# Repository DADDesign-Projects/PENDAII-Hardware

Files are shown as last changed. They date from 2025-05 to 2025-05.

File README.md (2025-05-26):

# PENDAII: Platform for Effects oN DAisy

Welcome to the **PENDAII** project! This repository contains the schematics and PCB layouts created with **KiCad 9.0** for a digital audio effects platform based on the **Daisy-Seed** board from **ElectroSmith**.

## Author

**DAD Design**

## Overview / Features

**PENDAII** is the second version of the PENDA platform. It introduces stereo processing and improved management of signal paths and power supplies.

**What’s New in PENDAII**:

- **Stereo processing**: a second audio channel has been added for a wider and more immersive sound experience.
- **Digital input volume control**: the input gain is now precisely adjustable via a digital potentiometer.
- **Digital Dry/Wet mix control**: the ratio between the processed (wet) and original (dry) signal is digitally managed.
- **100% analog Dry path**: although controlled digitally, the dry signal remains fully analog to preserve audio quality.

**General Features**:

- **Mono or Stereo Audio Input/Output**: flexible integration into various audio setups.
- **Two momentary footswitches**: for hands-free activation of effects.
- **2-inch SPI display**: clean and compact user interface (compatible with most ST7789 displays).
- **MIDI input**: allows control via external MIDI devices.
- **User controls**:
  - **4 encoders with push-button**: for parameter navigation and adjustment.
  - **3 analog potentiometers**: for direct control of parameters such as input level or Dry/Wet mix.

## Content

- The **Fab** directory contains all necessary files for fabrication.
- The **PENDAII-Hardware** directory contains the source files for the KiCad 9.0 project.

## Software

**PENDAII-Software** is a collection of audio effects built on an advanced software architecture, specifically designed for the PENDAII hardware platform.

[GitHub Repository](https://github.com/DADDesign-Projects/PENDAII-Software)

## Contributing

Contributions are welcome! If you'd like to suggest an improvement or fix an issue, feel free to open an *issue* or a *pull request*.

## License

This project is licensed under the **MIT License**.

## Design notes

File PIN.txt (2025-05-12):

Encoder0
A	PA0/D25
B	PD11/D26
SW	PA1/D24

Encoder1
A 	PA7/D18
B   PA6/D19
SW  PB1/D17

Encoder2
A	PA5/D22
B   PA0/D16
SW  PC0/D15

Encoder3
A   PB8/D11
B   PB9/D12
SW  PG10/D7

FootSwitch1 PG9/D27

FootSwitch2 PA2/D28

TFT_Reset   PC1/D20
TFT_DC		PC4/D21
TFT_MOSI	PB5/D10
TFT_SCK		PG11/D8

SSPI
SDATA       PC11/D1
CLK         PC10/D2
CS          PC9/D3
MUTE        D4

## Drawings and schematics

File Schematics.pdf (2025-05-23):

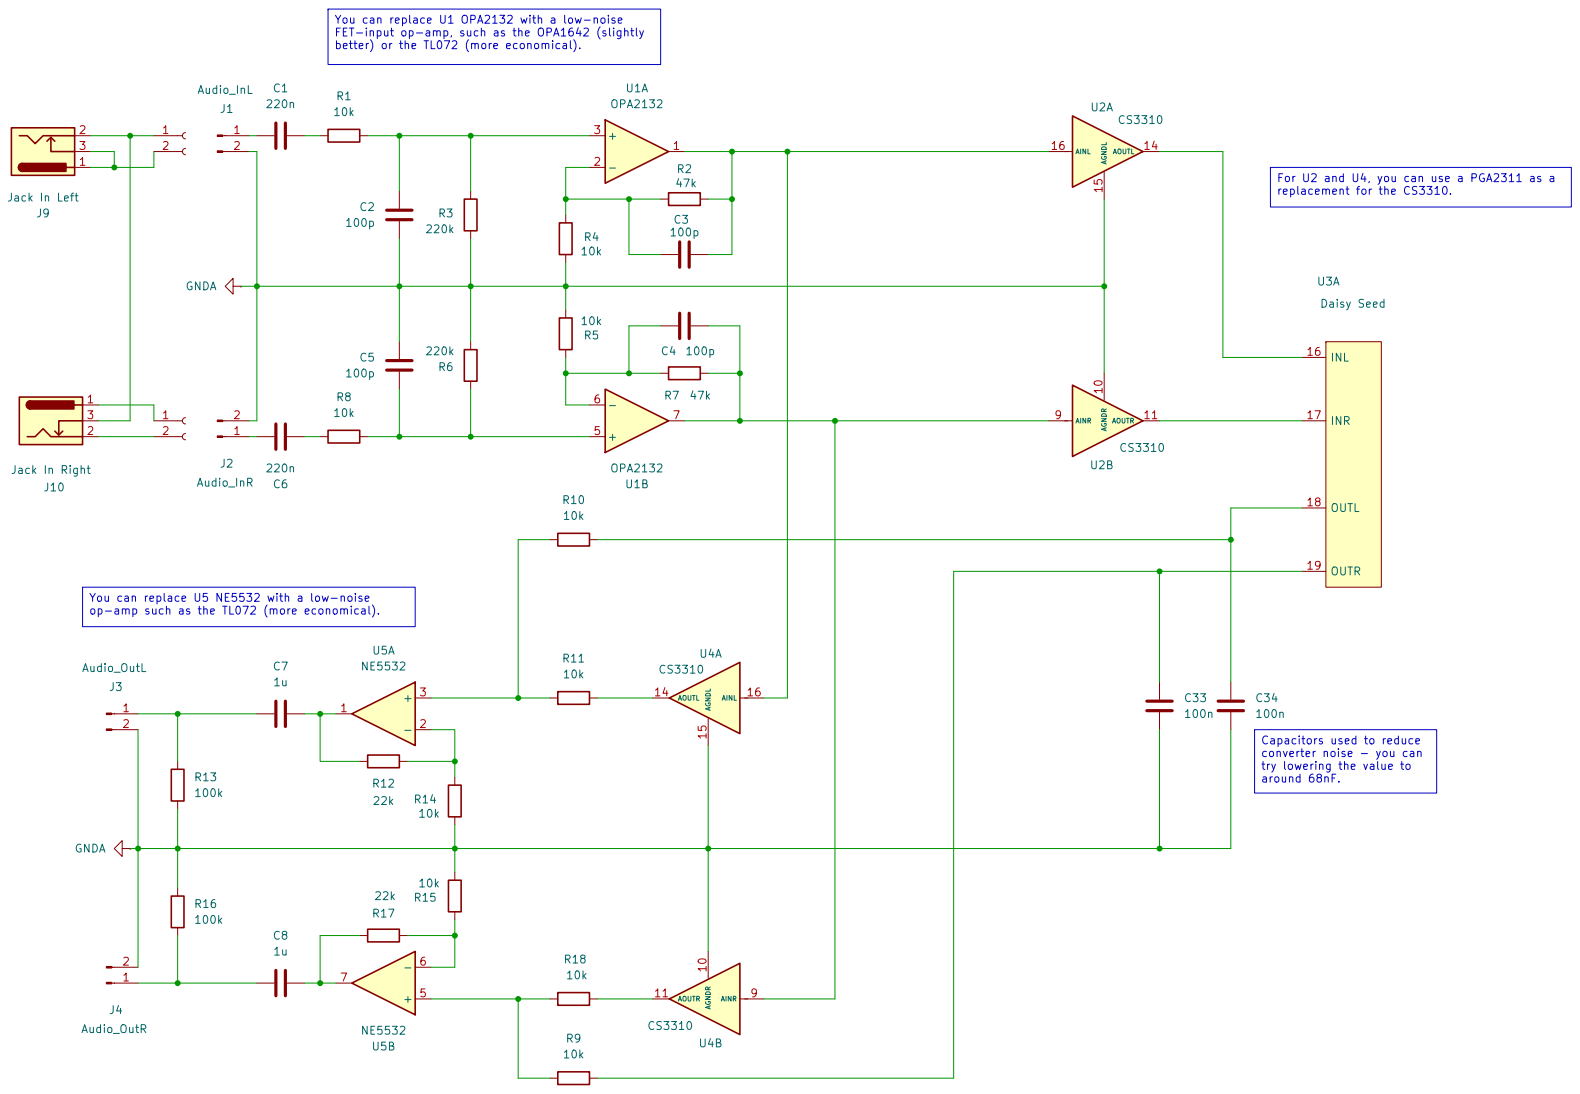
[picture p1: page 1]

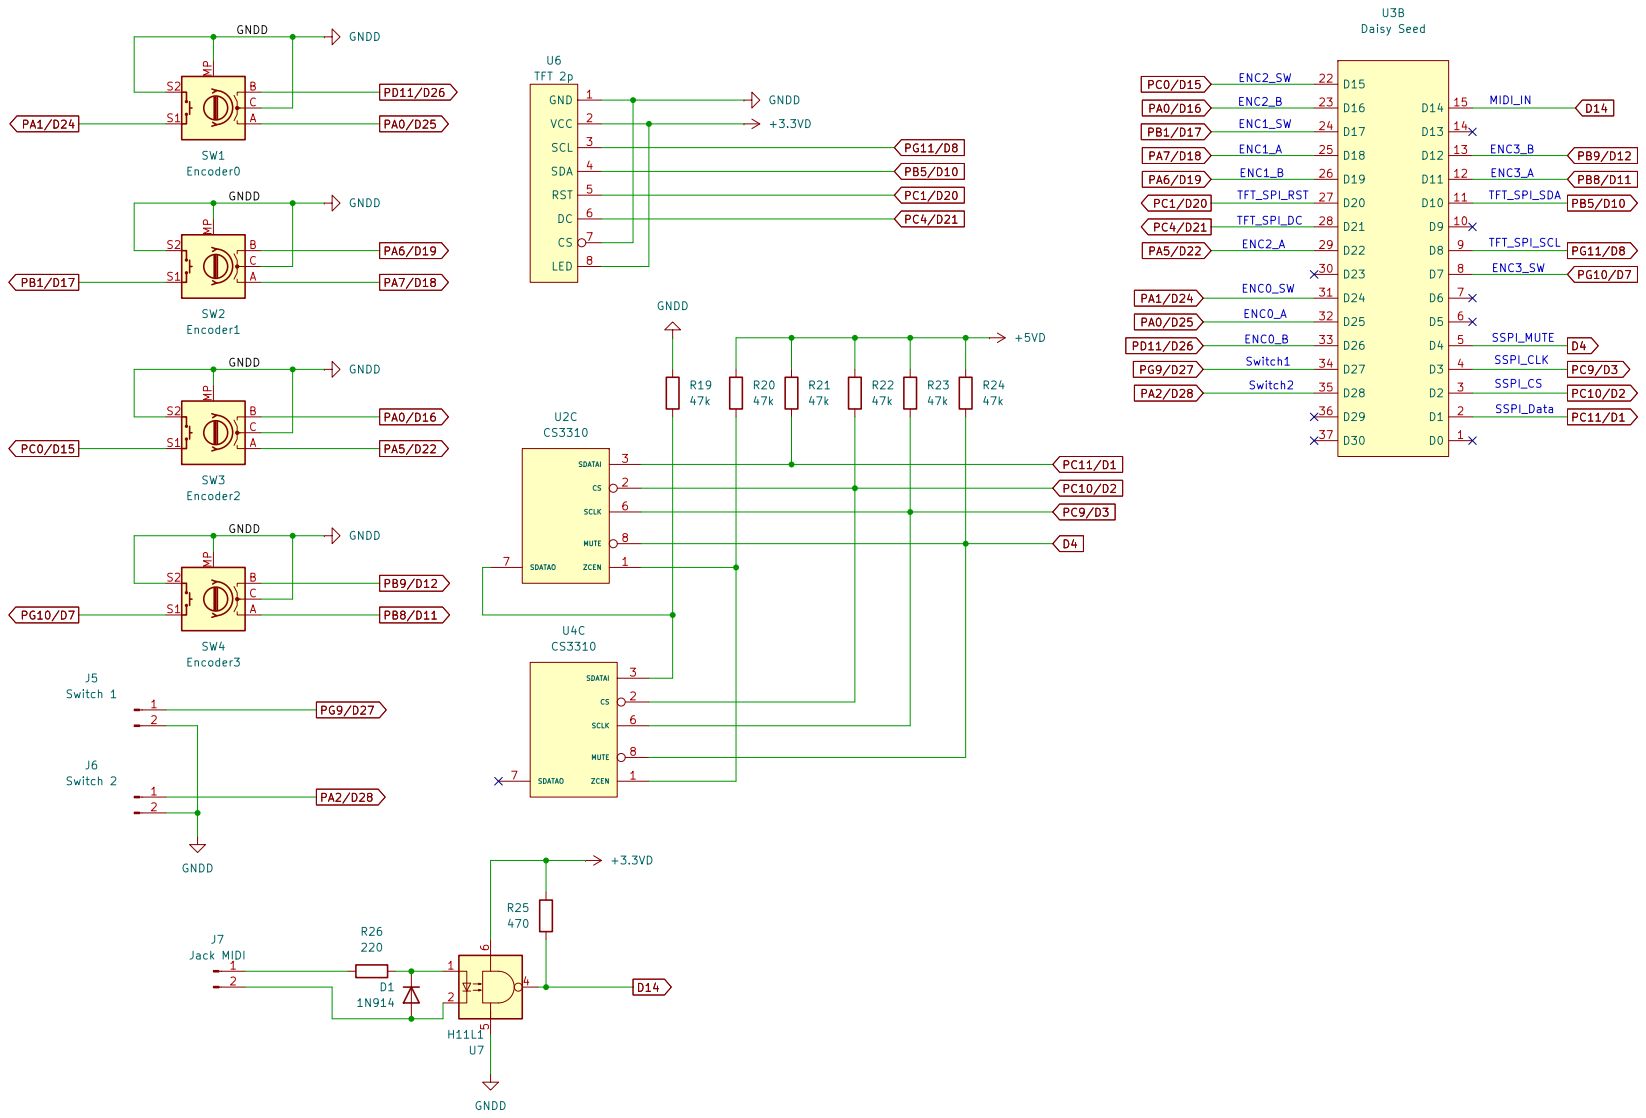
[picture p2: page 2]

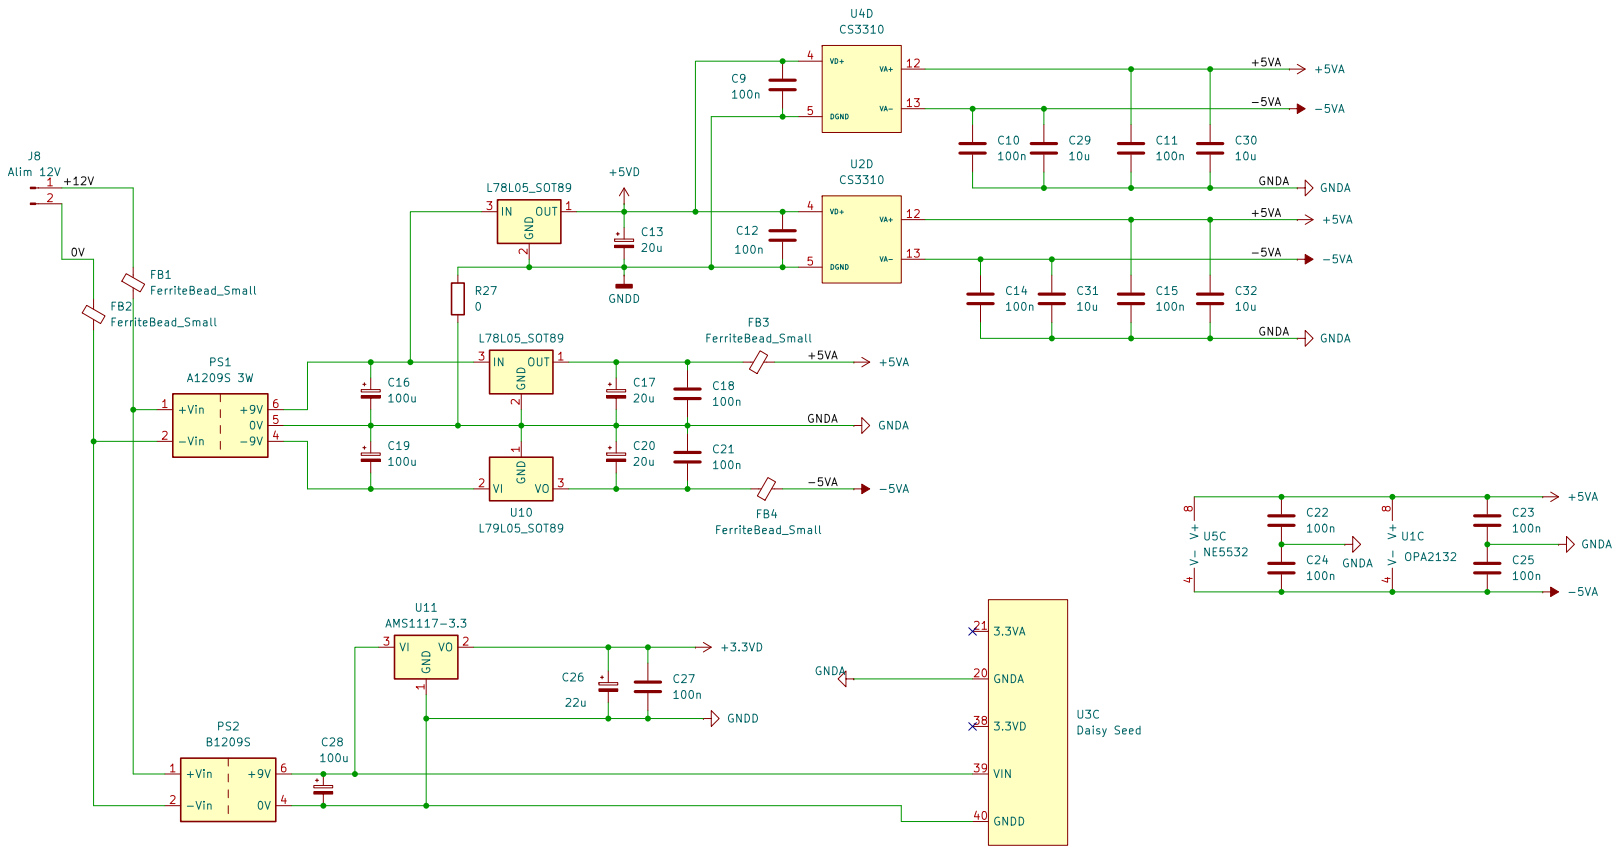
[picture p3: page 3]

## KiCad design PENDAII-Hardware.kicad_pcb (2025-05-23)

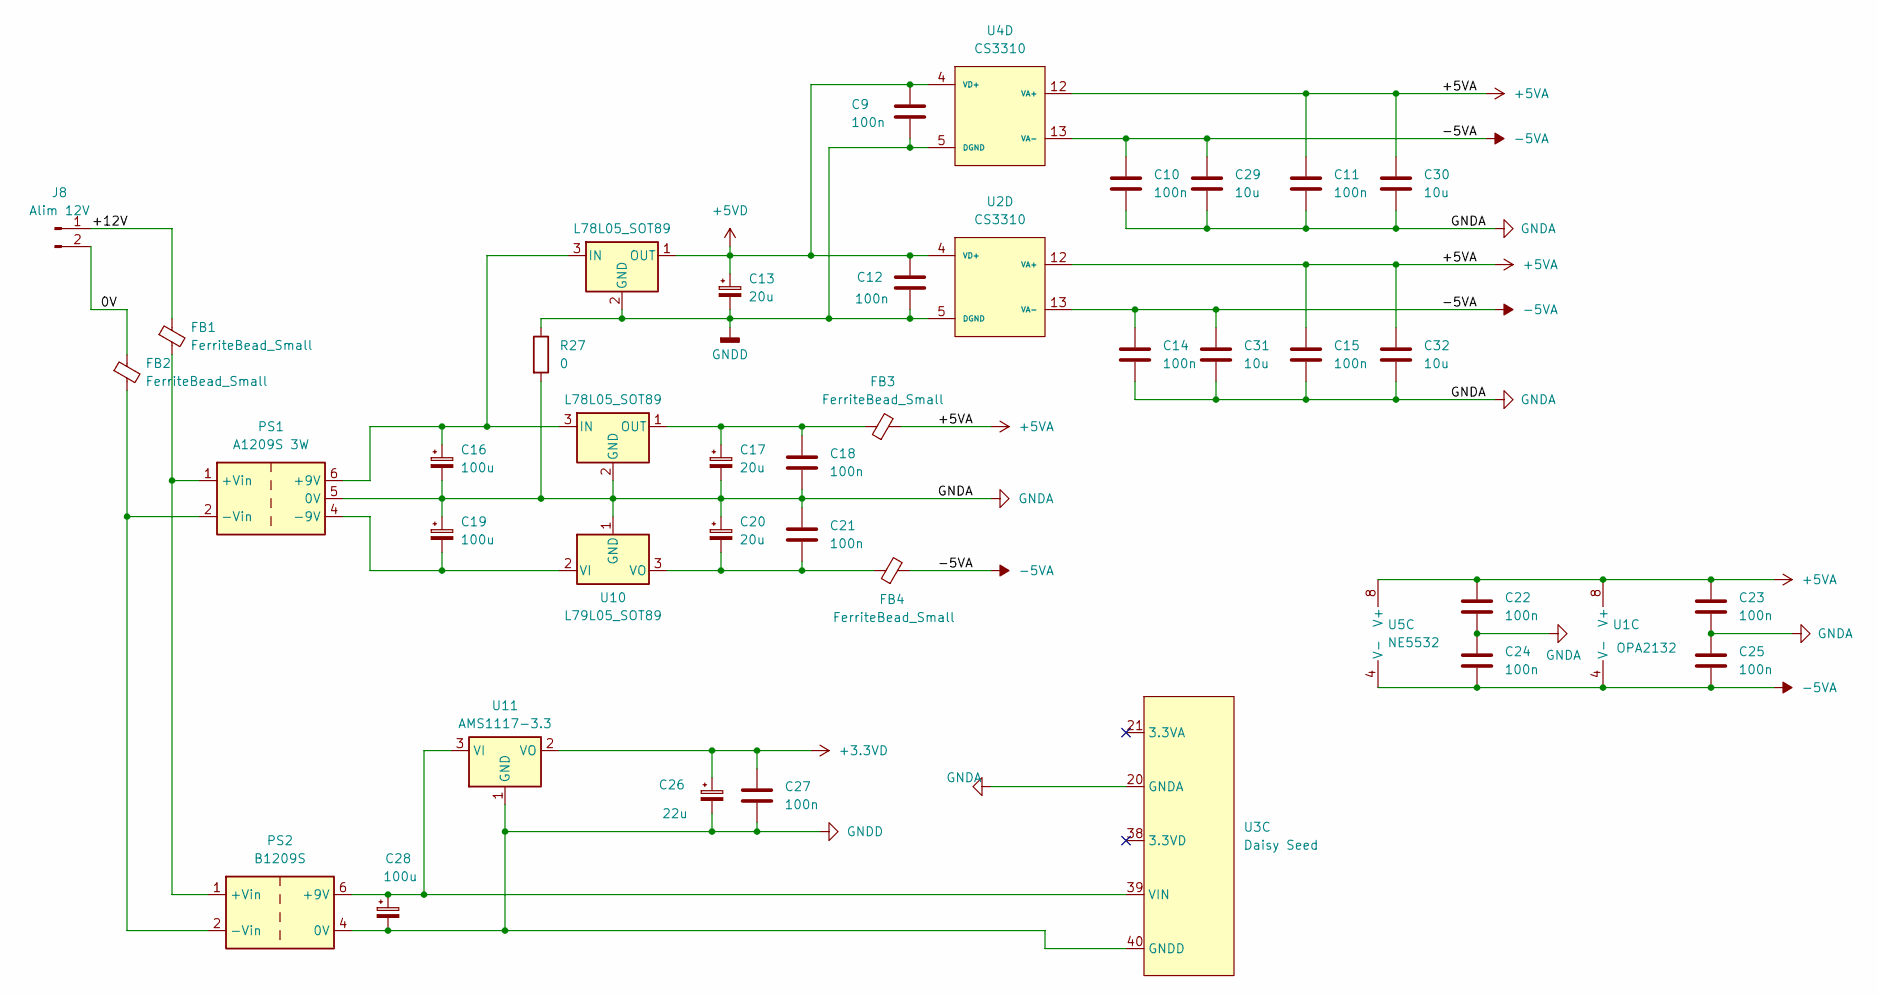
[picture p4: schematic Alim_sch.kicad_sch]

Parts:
C9, C10, C11, C12, C14, C15, C18, C21, C22, C23, C24, C25, C27: 100n; C_0805_2012Metric_Pad1.18x1.45mm_HandSolder
C13, C17, C20: 20u; CP_Elec_5x5.4
C16, C19, C28: 100u; CP_Elec_6.3x7.7
C26: 22u; CP_Elec_5x5.4
C29, C30, C31, C32: 10u; C_1206_3216Metric_Pad1.33x1.80mm_HandSolder
FB1, FB2: FerriteBead_Small; L_1206_3216Metric_Pad1.22x1.90mm_HandSolder
FB3, FB4: FerriteBead_Small; L_0805_2012Metric_Pad1.15x1.40mm_HandSolder
J8: Alim 12V; PinHeader_1x02_P2.54mm_Vertical
PS1: A1209S 3W; Converter_DCDC_TRACO_TBA2-xxxx_Dual_THT
PS2: B1209S; Converter_DCDC_TRACO_TBA2-xxxx_Single_THT
R27: 0; R_1206_3216Metric_Pad1.30x1.75mm_HandSolder
U1: OPA2132; SOP-8_3.76x4.96mm_P1.27mm
U2, U4: CS3310; SOIC-16W_7.5x10.3mm_P1.27mm
U3: Daisy Seed; DIP-40_W15.24mm_Socket_LongPads
U5: NE5532; SOP-8_3.76x4.96mm_P1.27mm
U8, U9: L78L05_SOT89; SOT-89-3
U10: L79L05_SOT89; SOT-89-3
U11: AMS1117-3.3; SOT-223-3_TabPin2

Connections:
+3.3VD: C26.1, C27.1, U11.2 (VO); also elsewhere on the board
+5VA: C11.1, C15.1, C22.1, C23.1, C30.1, C32.1, FB3.2, U1.8 (V+), U2.12 (VA+), U4.12 (VA+), U5.8 (V+)
+5VD: C9.1, C12.1, C13.1, U2.4 (VD+), U4.4 (VD+), U8.1 (OUT); also elsewhere on the board
-5VA: C10.1, C14.1, C24.2, C25.2, C29.1, C31.1, FB4.2, U1.4 (V-), U2.13 (VA-), U4.13 (VA-), U5.4 (V-)
/Alim/0V: FB2.1, J8.2
/Alim/+12V: FB1.1, J8.1
GNDA: C10.2, C11.2, C14.2, C15.2, C16.2, C17.2, C18.2, C19.1, C20.1, C21.1, C22.2, C23.2, C24.1, C25.1, C29.2, C30.2, C31.2, C32.2, PS1.5 (0V), R27.2, U3.20 (GNDA), U9.2 (GND), U10.1 (GND); also elsewhere on the board
GNDD: C9.2, C12.2, C13.2, C26.2, C27.2, C28.2, PS2.4 (0V), R27.1, U2.5 (DGND), U3.40 (GNDD), U4.5 (DGND), U8.2 (GND), U11.1 (GND); also elsewhere on the board
unnamed: C16.1, PS1.6 (+9V), U8.3 (IN), U9.3 (IN)
unnamed: FB1.2, PS1.1 (+Vin), PS2.1 (+Vin)
unnamed: C19.2, PS1.4 (-9V), U10.2 (VI)
unnamed: FB2.2, PS1.2 (-Vin), PS2.2 (-Vin)
unnamed: C28.1, PS2.6 (+9V), U3.39 (VIN), U11.3 (VI)
unnamed: C17.1, C18.1, FB3.1, U9.1 (OUT)
unnamed: C20.2, C21.2, FB4.1, U10.3 (VO)

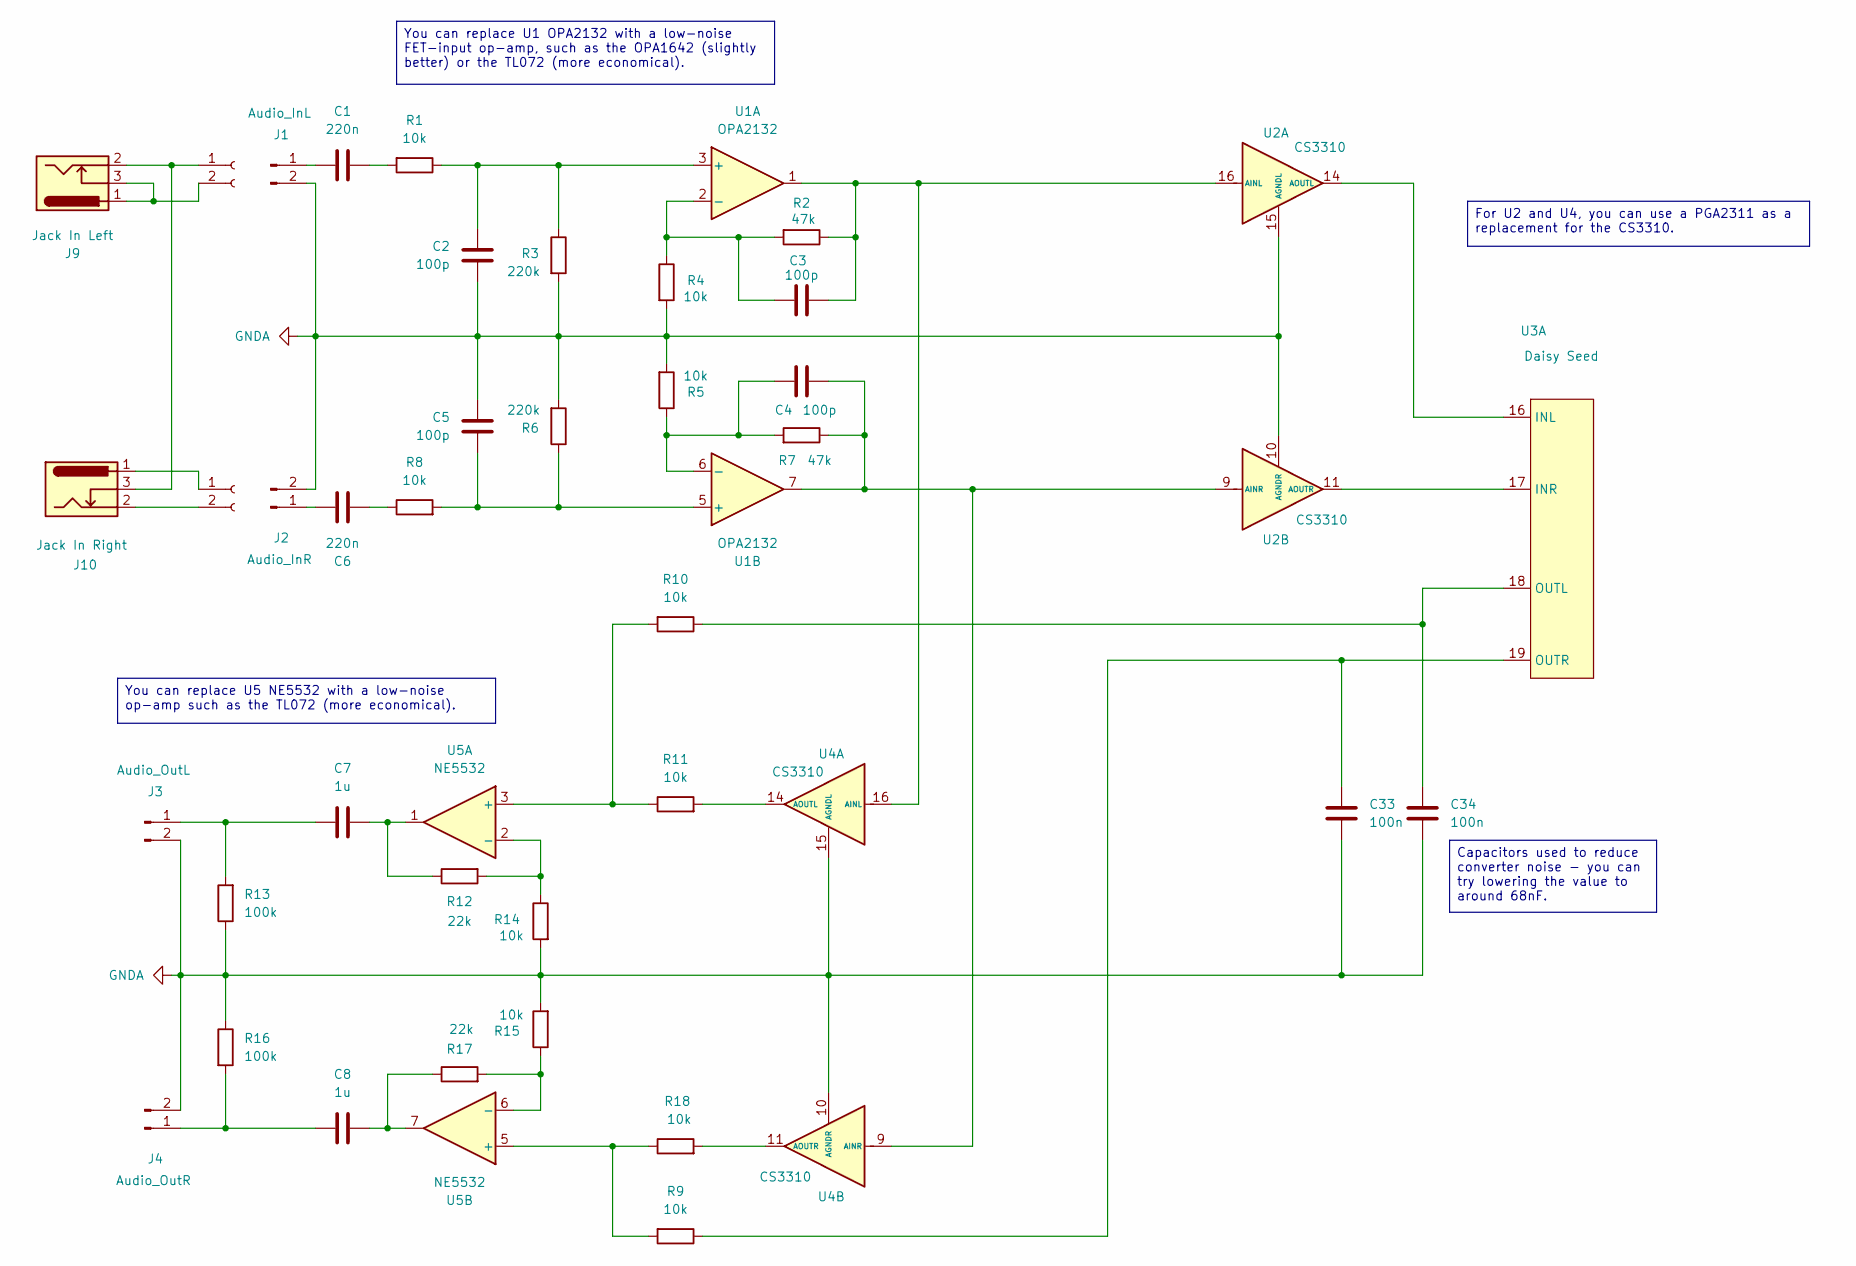
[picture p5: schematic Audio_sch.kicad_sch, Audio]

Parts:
C1, C6: 220n; C_1206_3216Metric_Pad1.33x1.80mm_HandSolder
C2, C3, C4, C5: 100p; C_1206_3216Metric_Pad1.33x1.80mm_HandSolder
C7, C8: 1u; C_1206_3216Metric_Pad1.33x1.80mm_HandSolder
C33, C34: 100n; C_0805_2012Metric_Pad1.18x1.45mm_HandSolder
J1: Audio_InL; PinHeader_1x02_P2.54mm_Vertical
J2: Audio_InR; PinHeader_1x02_P2.54mm_Vertical
J3: Audio_OutL; PinHeader_1x02_P2.54mm_Vertical
J4: Audio_OutR; PinHeader_1x02_P2.54mm_Vertical
J9: Jack In Left
J10: Jack In Right
J11: Conn_01x02_Socket
J12: (no value)
R1, R4, R5, R8, R9, R10, R11, R14, R15, R18: 10k; R_1206_3216Metric_Pad1.30x1.75mm_HandSolder
R2, R7: 47k; R_1206_3216Metric_Pad1.30x1.75mm_HandSolder
R3, R6: 220k; R_1206_3216Metric_Pad1.30x1.75mm_HandSolder
R12, R17: 22k; R_1206_3216Metric_Pad1.30x1.75mm_HandSolder
R13, R16: 100k; R_1206_3216Metric_Pad1.30x1.75mm_HandSolder
U1: OPA2132; SOP-8_3.76x4.96mm_P1.27mm
U2, U4: CS3310; SOIC-16W_7.5x10.3mm_P1.27mm
U3: Daisy Seed; DIP-40_W15.24mm_Socket_LongPads
U5: NE5532; SOP-8_3.76x4.96mm_P1.27mm

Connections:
GNDA: C2.1, C5.1, C33.2, C34.2, J1.2, J2.2, J3.2, J4.2, R3.2, R4.2, R5.2, R6.2, R13.1, R14.2, R15.2, R16.1, U2.10 (AGNDR), U2.15 (AGNDL), U4.10 (AGNDR), U4.15 (AGNDL); also elsewhere on the board
unnamed: C1.2, R1.2
unnamed: C6.2, R8.1
unnamed: C7.2, R12.1, U5.1
unnamed: C8.2, R17.1, U5.7
unnamed: C1.1, J1.1
unnamed: C6.1, J2.1
unnamed: C7.1, J3.1, R13.2
unnamed: C8.1, J4.1, R16.2
unnamed: J10.1, J12.1
unnamed: J10.2, J12.2
unnamed: J9.2, J10.3, J11.1
unnamed: J9.1, J9.3, J11.2
unnamed: C2.2, R1.1, R3.1, U1.3 (+)
unnamed: C3.1, R2.2, R4.1, U1.2 (-)
unnamed: C5.2, R6.1, R8.2, U1.5 (+)
unnamed: C4.1, R5.1, R7.2, U1.6 (-)
unnamed: C3.2, R2.1, U1.1, U2.16 (AINL), U4.16 (AINL)
unnamed: U2.14 (AOUTL), U3.16 (INL)
unnamed: C4.2, R7.1, U1.7, U2.9 (AINR), U4.9 (AINR)
unnamed: U2.11 (AOUTR), U3.17 (INR)
unnamed: C34.1, R10.1, U3.18 (OUTL)
unnamed: C33.1, R9.1, U3.19 (OUTR)
unnamed: R11.2, U4.14 (AOUTL)
unnamed: R18.2, U4.11 (AOUTR)
unnamed: R10.2, R11.1, U5.3 (+)
unnamed: R12.2, R14.1, U5.2 (-)
unnamed: R9.2, R18.1, U5.5 (+)
unnamed: R15.1, R17.2, U5.6 (-)

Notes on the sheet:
You can replace U5 NE5532 with a low-noise op-amp such as the TL072 (more economical).
You can replace U1 OPA2132 with a low-noise FET-input op-amp, such as the OPA1642 (slightly better) or the TL072 (more economical).
For U2 and U4, you can use a PGA2311 as a replacement for the CS3310.
Capacitors used to reduce converter noise - you can try lowering the value to around 68nF.

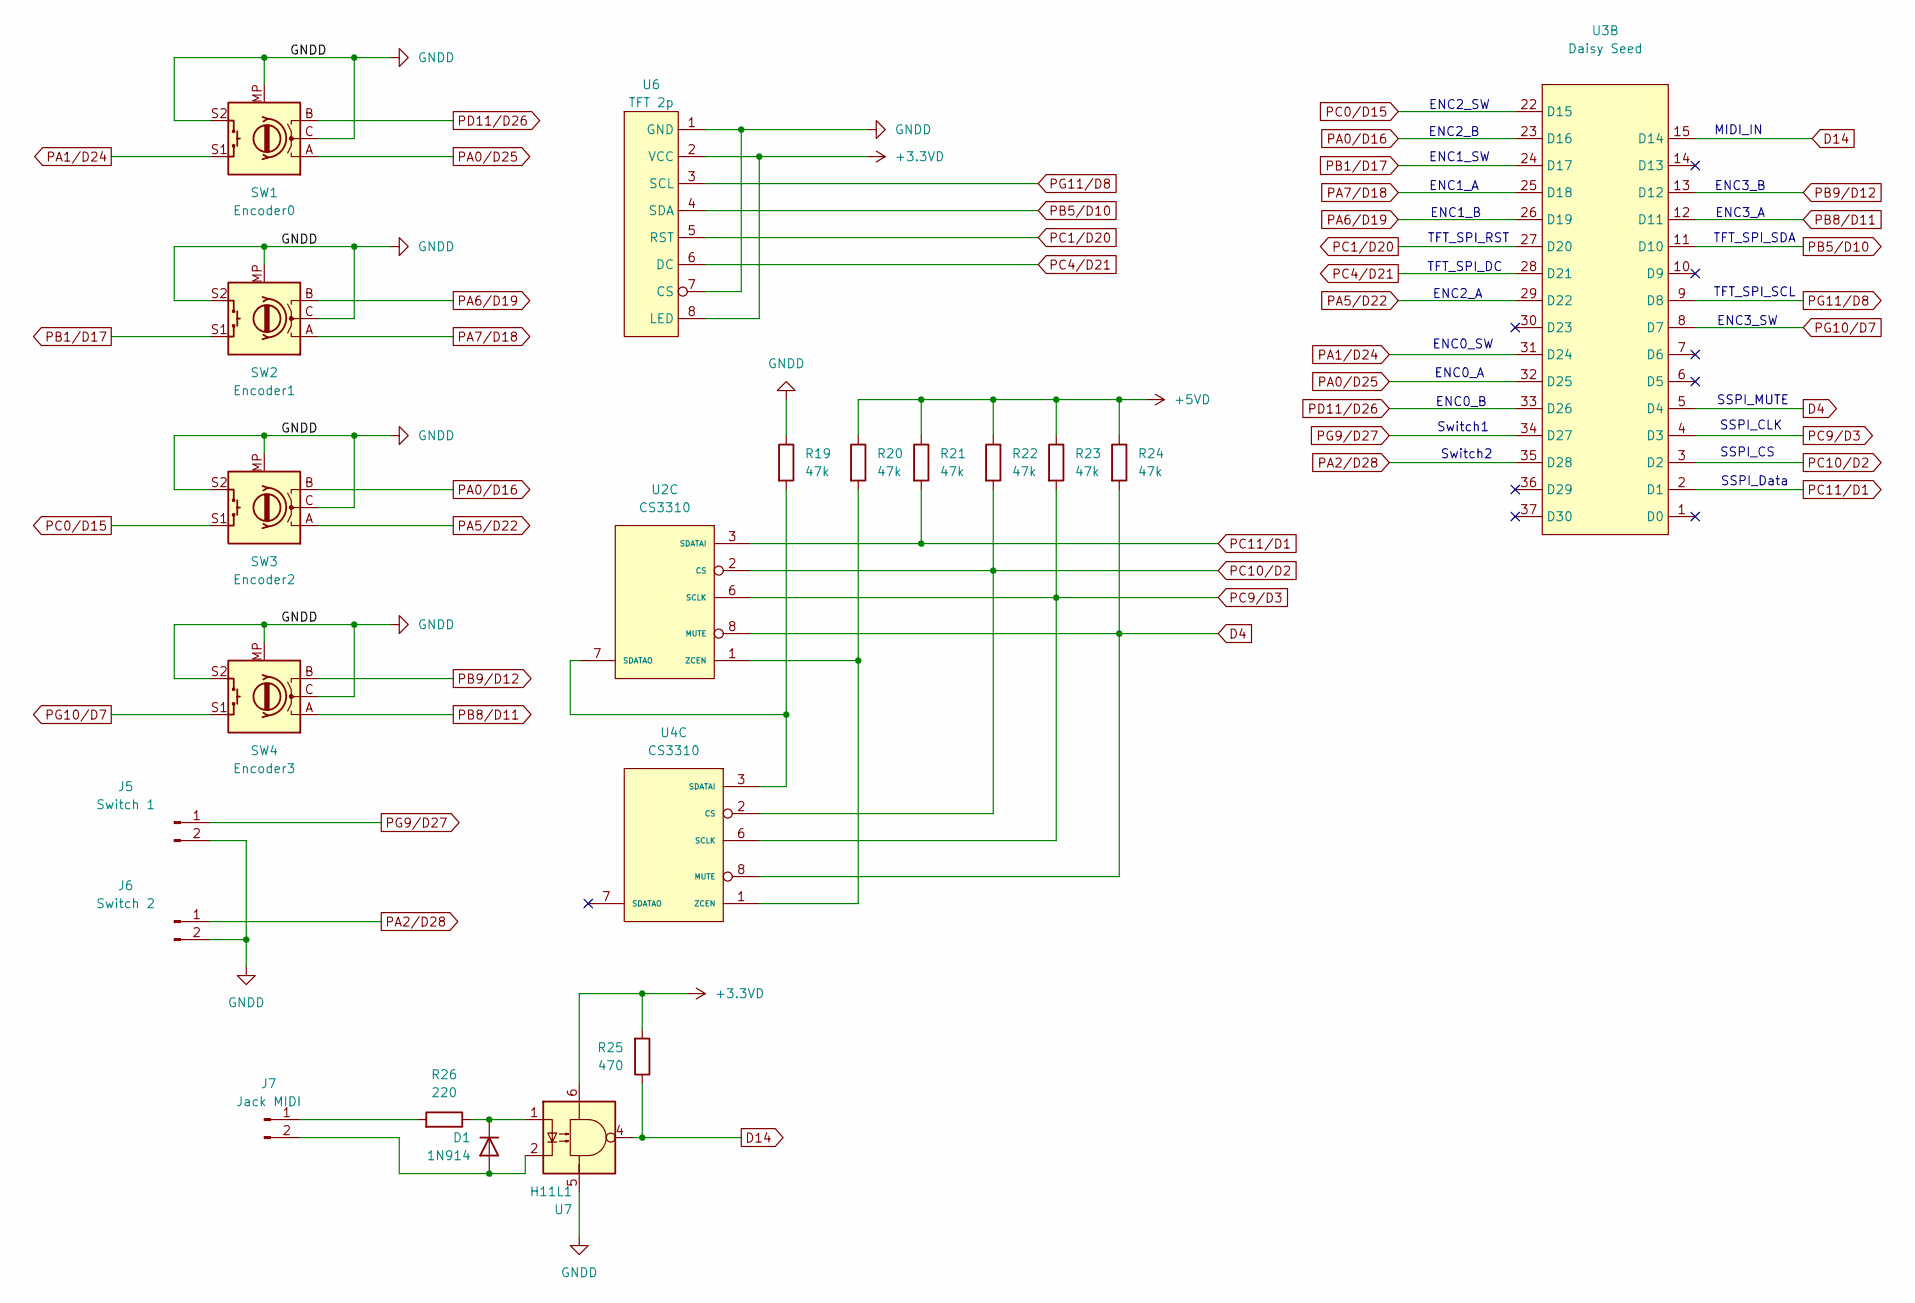
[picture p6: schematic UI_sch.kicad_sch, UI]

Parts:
D1: 1N914; D_DO-35_SOD27_P7.62mm_Horizontal
J5: Switch 1; PinHeader_1x02_P2.54mm_Vertical
J6: Switch 2; PinHeader_1x02_P2.54mm_Vertical
J7: Jack MIDI; PinHeader_1x02_P2.54mm_Vertical
R19, R20, R21, R22, R23, R24: 47k; R_1206_3216Metric_Pad1.30x1.75mm_HandSolder
R25: 470; R_Axial_DIN0204_L3.6mm_D1.6mm_P7.62mm_Horizontal
R26: 220; R_Axial_DIN0204_L3.6mm_D1.6mm_P7.62mm_Horizontal
SW1: Encoder0; RotaryEncoder_Alps_EC11E-Switch_Vertical_H20mm
SW2: Encoder1; RotaryEncoder_Alps_EC11E-Switch_Vertical_H20mm
SW3: Encoder2; RotaryEncoder_Alps_EC11E-Switch_Vertical_H20mm
SW4: Encoder3; RotaryEncoder_Alps_EC11E-Switch_Vertical_H20mm
U2, U4: CS3310; SOIC-16W_7.5x10.3mm_P1.27mm
U3: Daisy Seed; DIP-40_W15.24mm_Socket_LongPads
U6: TFT 2p; PinSocket_1x08_P2.54mm_Vertical
U7: H11L1; DIP-6_W7.62mm

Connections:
+3.3VD: R25.2, U6.2 (VCC), U6.8 (LED), U7.6; also elsewhere on the board
+5VD: R20.1, R21.1, R22.1, R23.1, R24.1; also elsewhere on the board
D4: R24.2, U2.8 (MUTE), U3.5 (D4), U4.8 (MUTE)
D14: R25.1, U3.15 (D14), U7.4
GNDD: J5.2, J6.2, R19.1, SW1.C, SW1.MP, SW1.S2, SW2.C, SW2.MP, SW2.S2, SW3.C, SW3.MP, SW3.S2, SW4.C, SW4.MP, SW4.S2, U6.1 (GND), U6.7 (CS), U7.5; also elsewhere on the board
unnamed: D1.2 (A), J7.2, U7.2
unnamed: D1.1 (K), R26.1, U7.1
unnamed: J7.1, R26.2
unnamed: R19.2, U2.7 (SDATAO), U4.3 (SDATAI)
unnamed: R20.2, U2.1 (ZCEN), U4.1 (ZCEN)
PA0/D16: SW3.B, U3.23 (D16)
PA0/D25: SW1.A, U3.32 (D25)
PA1/D24: SW1.S1, U3.31 (D24)
PA2/D28: J6.1, U3.35 (D28)
PA5/D22: SW3.A, U3.29 (D22)
PA6/D19: SW2.B, U3.26 (D19)
PA7/D18: SW2.A, U3.25 (D18)
PB1/D17: SW2.S1, U3.24 (D17)
PB5/D10: U3.11 (D10), U6.4 (SDA)
PB8/D11: SW4.A, U3.12 (D11)
PB9/D12: SW4.B, U3.13 (D12)
PC0/D15: SW3.S1, U3.22 (D15)
PC1/D20: U3.27 (D20), U6.5 (RST)
PC4/D21: U3.28 (D21), U6.6 (DC)
PC9/D3: R23.2, U2.6 (SCLK), U3.4 (D3), U4.6 (SCLK)
PC10/D2: R22.2, U2.2 (CS), U3.3 (D2), U4.2 (CS)
PC11/D1: R21.2, U2.3 (SDATAI), U3.2 (D1)
PD11/D26: SW1.B, U3.33 (D26)
PG9/D27: J5.1, U3.34 (D27)
PG10/D7: SW4.S1, U3.8 (D7)
PG11/D8: U3.9 (D8), U6.3 (SCL)

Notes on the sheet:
ENC1_B
Switch1
ENC1_A
TFT_SPI_DC
Switch2
TFT_SPI_SCL
ENC2_SW
ENC2_A
ENC0_SW
ENC2_B
ENC3_SW
ENC3_A
ENC0_B
ENC3_B
SSPI_MUTE
TFT_SPI_RST
SSPI_CLK
SSPI_Data
ENC1_SW
TFT_SPI_SDA
SSPI_CS
MIDI_IN
ENC0_A

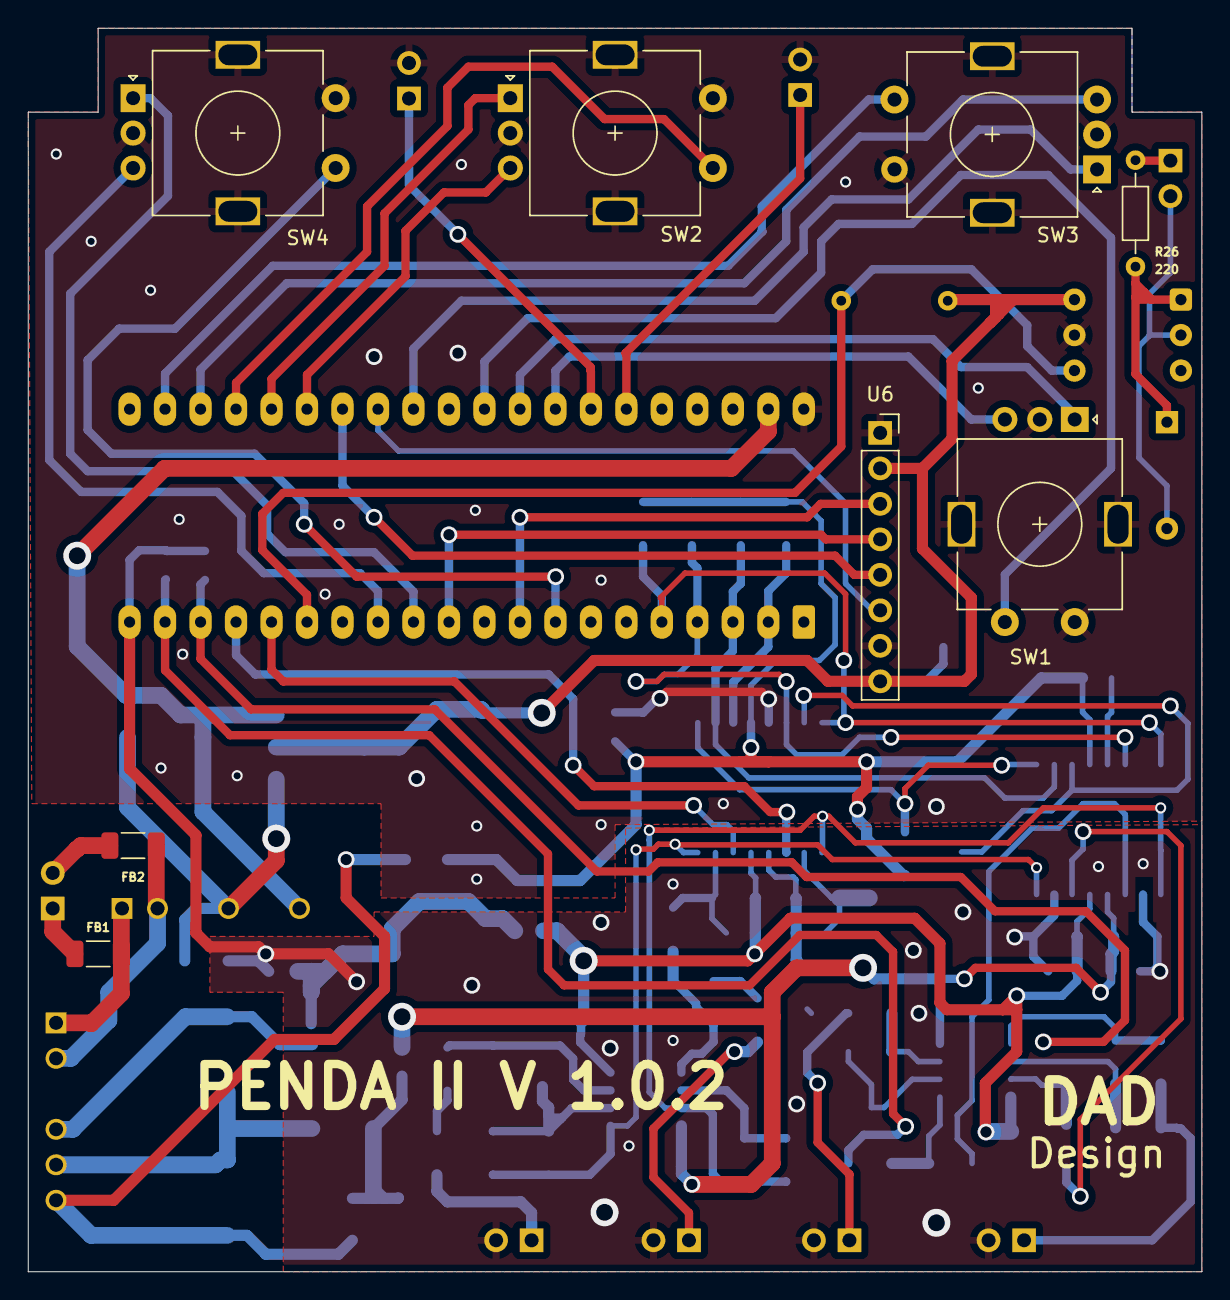
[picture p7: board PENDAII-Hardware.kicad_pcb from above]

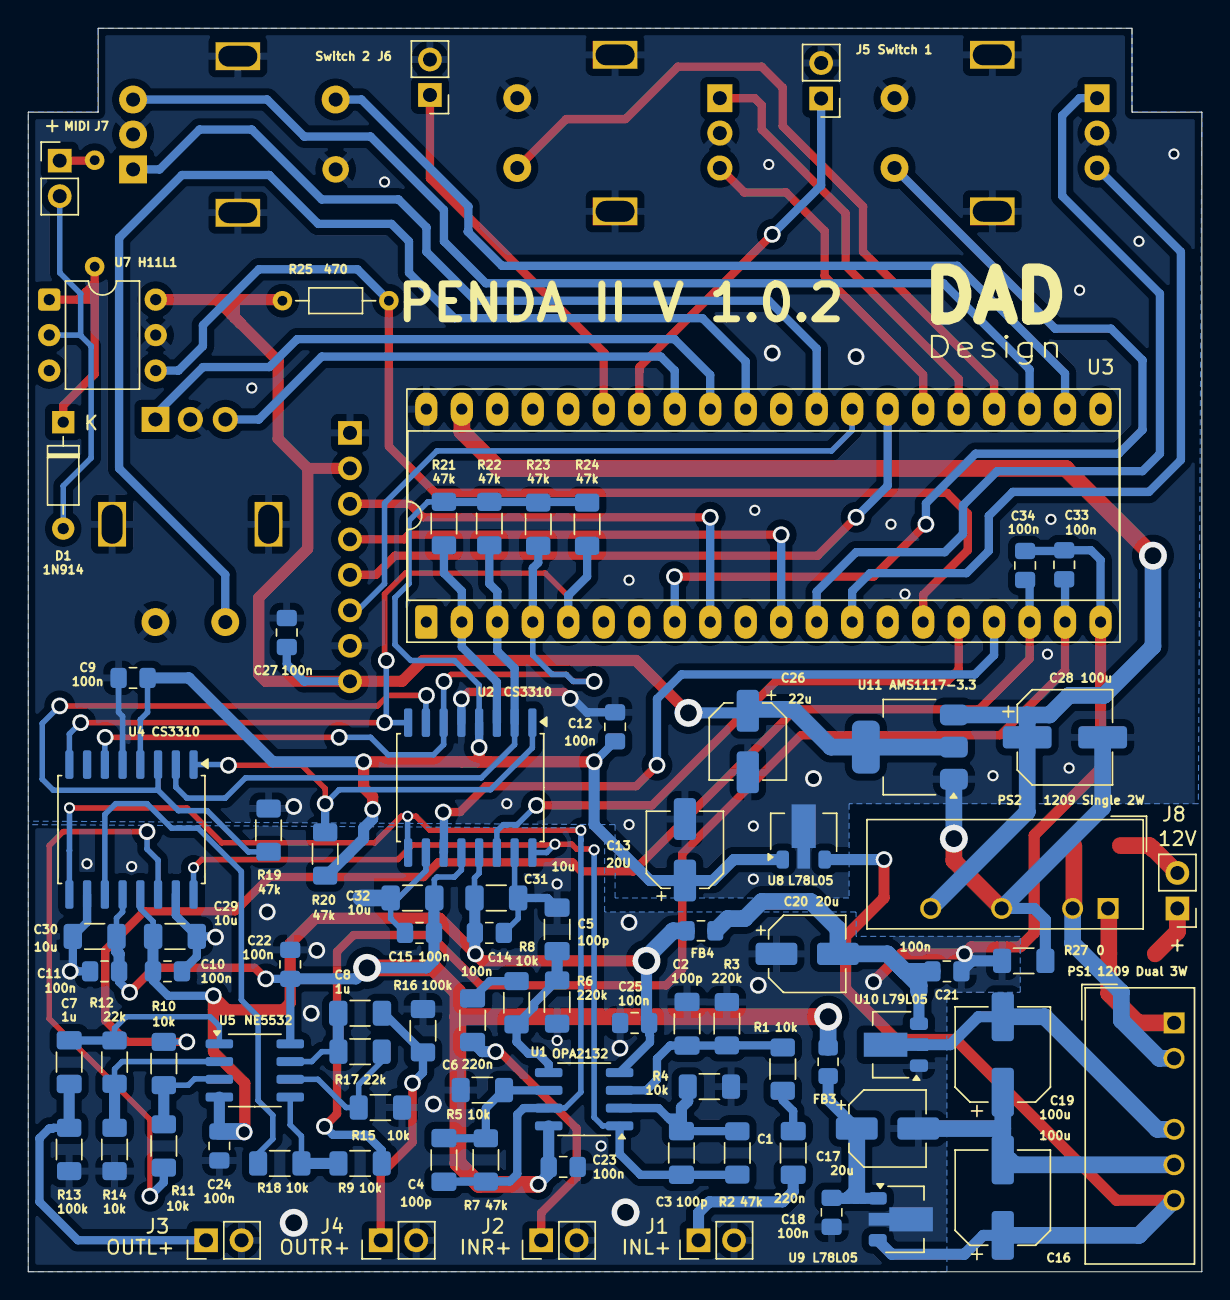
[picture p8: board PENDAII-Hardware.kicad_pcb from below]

Board: 2 copper layers, 84.0 x 89.0 mm, 91 parts (83 on the bottom side), 67 nets.
